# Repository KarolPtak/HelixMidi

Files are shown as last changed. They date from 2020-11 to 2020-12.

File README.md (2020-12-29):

# HelixMidi

## This is a DIY midi footswitch controller for the line6 helix / hx stomp (or actually any midi device).

Short demo: https://youtu.be/-W3b5MKsnIc

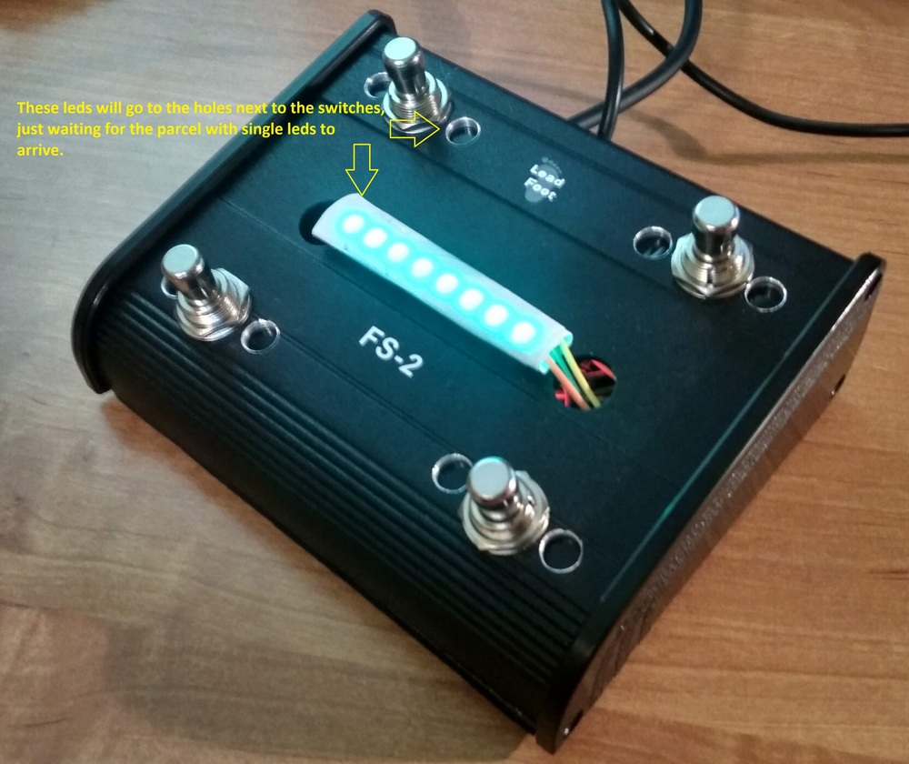
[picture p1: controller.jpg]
Controller


I did it when it's turned out that I neeed more than 3 footswitches ;-) , and the price of stock midi controllers was too high. More likely I'd sell the stomp and buy helix lt instead, if I had to pay for the controller.

It offers 6 different pages (modes), and covers nearly everything that the hx stomp can accept through the midi :)
It is powered directly from USB, works fine with hx stomp, no buzz/hum

- basic - 4 'classic' switches
- basic+ - 3 'classic' switches + tap/tempo
- preset change - Fs4,5 emulation + 1 'classic' + tap/tempo
- snapshot change - 3 snapshot switches + tap/tempo
- looper 1 - record/overdub, play/stop, undo/redo, tap/tempo
- looper 2 - record/overdub, play, stop, undo/redo

- tuner on/off always available when long pressing fs2

## Brief user manual :) :

You can cycle between basic, basic+, preset and snapshot change by long pressing fs1 and fs2 simultaneously.
Clycle between basic, looper 1, looper 2 by long pressing fs3 and fs4 simultaneously.
Each page has it's own color set - I've tried to reflect hx stomp colors as closely as possible :).

Current page is saved in memory, so next time you turn on the controller, it will go back to it.

Footswitch functions in particular page:
- Basic : fs1-4 - 'classic switches' (midi cc codes 100-103)
- Basic+ : fs1-3 - 'classic switches' (midi cc codes 100-102), fs4 - tap/tempo
- Preset change: fs1 - Fs4 emulation, fs2 - 'classic switch' (midi cc code 101), fs3 - Fs5 emulation, fs4 - tap/tempo
- Snapshot change: fs1-3 - snapshot 1-3, fs4 - tap/tempo
- Looper 1 - fs1: play/stop, fs2 - undo/redo, fs3 - record/overdub, fs4 - tap/tempo
- Looper 2 - fs1: stop, fs2 - undo/redo, fs3 - play, fs4 - record/overdub

In the looper modes leds function is a bit different, and it displays if the looper is active, and if record/overdub is in progres.
So eg. after hitting record/overdub (first time) leds indicating looper and record activation will be lit, and then, if You hit the play switch, the record led will be shut. However it's not 100% accurate - (eg. undo/redo hit just after recording is started for the first time seems to turn the looper in the hx stomp off, but it's the best I could do ;-)

Tap tempo blinking - sadly my led blinking implementation did not keep up the same tempo as the stomp. Probably it was implemented too naive way ;), or just a real time clock is needed to do it? hmm...

## Programming

3 external libraries are used for midi, ledstrip and button handling. You can add them via Arduino IDE -> Tools -> Manage Libraries...

Add:
- MIDI Library (by Francois Best, lathoub)
- Freenove WS2812B RGBLED Controller
- ezButton

Sketch uses 8194 bytes (26%) of program storage space. Maximum is 30720 bytes.
Global variables use 740 bytes (36%) of dynamic memory, leaving 1308 bytes for local variables. Maximum is 2048 bytes.

## Elements used

- Arduino nano - https://www.ebay.com/itm/ATmega328P-Micro-Controller-CH340G-Driver-For-Arduino-5V-16MHz-Nano-V3-0-USB/283932008665
- 4 Footswitches - https://www.ebay.com/itm/2Pin-SPST-Momentary-Touch-Push-Button-Stomp-Foot-Pedal-Electric-Guitar-Switch-SC/163157135937
- Ledstrip WS2812B - 8 leds in series, 2 per one switch - like these, just cut it to single leds (they are ready for this): https://www.ebay.com/itm/WS2812B-5V-5050-RGB-LED-Strip-1-5M-30-60-144-150-300-Leds-Individual-Addressable/254700428516
- Case (any, actually) - I used that: https://www.thomann.de/pl/lead_foot_fs2.htm
- Midi cable / socket - I used that: https://www.thomann.de/pl/the_sssnake_sk366-1_blk_midi_kabel.htm and soldered its wires to arduino

Total cost of elements (except the case) was c.a. 23$.

## Wiring
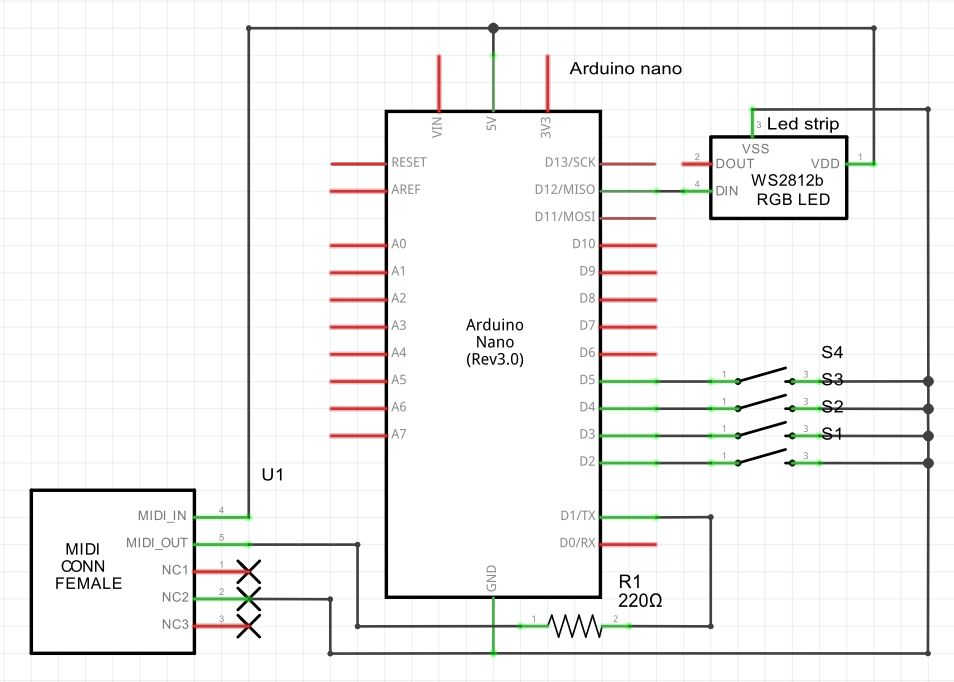
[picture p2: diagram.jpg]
Diagram


In my case (huh, 'case' ;D) the wiring looks like this - pretty simple (only on the photo it looks like hundreds of wires :P ), the arduino is in a heat shrink tubing, and attached to the case with double sided tape

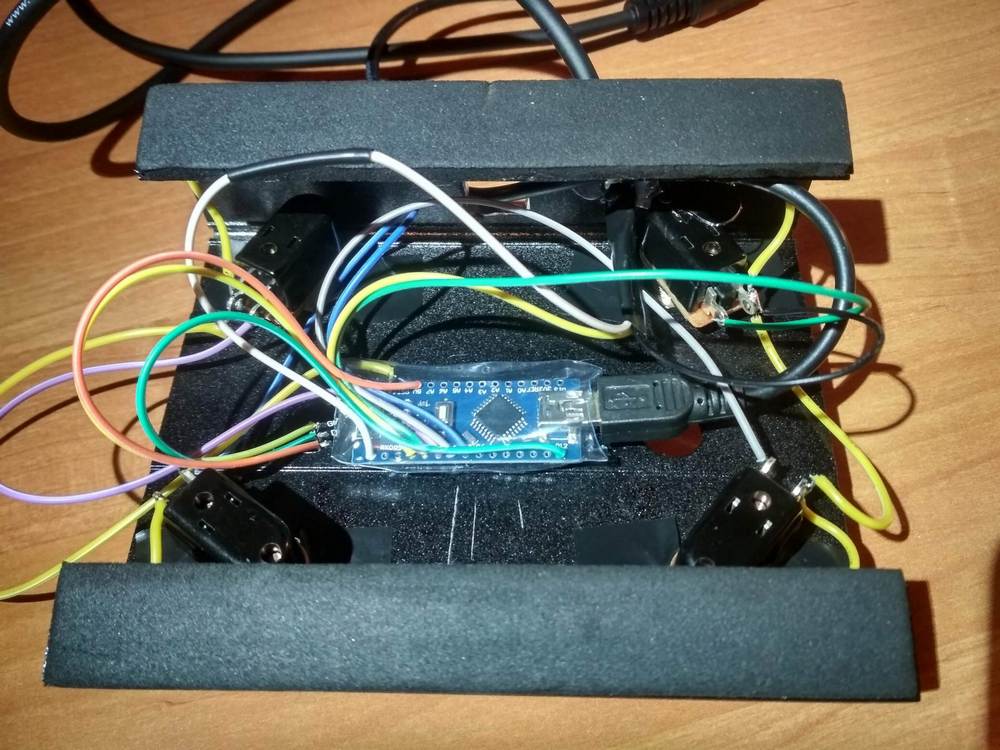
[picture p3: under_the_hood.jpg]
Wiring


## Misc

- If you wonder what is the correct order of pins in the midi socket/plug, this image should solve Your problems (helped me a lot)

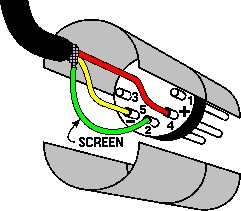
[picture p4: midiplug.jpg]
Midi plug
  
  
  it comes from http://www.philrees.co.uk/midiplug.htm 
  
- It looks like this together with the hx stomp

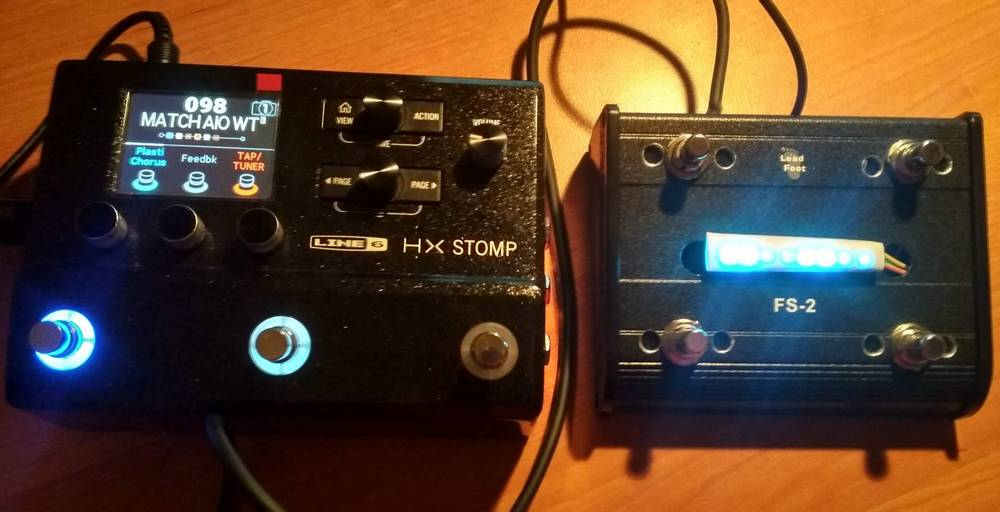
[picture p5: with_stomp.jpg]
Together with hx stomp With hx stomp
  

## TODO

- [ ] Tap/tempo and looper mode
- [ ] Install single leds next to the stomp when they arrive ;) And fill their holes with some transparent, or opaline resin to disperse the led light gently.

## Info from hx stomp instruction

CC message ids restricted by line6 (special purpose):

```
0	n/a Bank MSB (unused, but reserved)
1	0-127 Emulates EXP 1 Pedal
2	0-127 Emulates EXP 2 Pedal
3	0-127 Additional global MIDI commands
32	n/a Bank LSB (unused, but reserved)
49	0-127 Emulates FS1
50	0-127 Emulates FS2
51	0-127 Emulates FS3
52	0-127 Emulates FS4
53	0-127 Emulates FS5
54	0-127 Additional global MIDI commands
55	0-127 Additional global MIDI commands
56	0-127 Additional global MIDI commands
57	0-127 Additional global MIDI commands
58	0-127 Additional global MIDI commands
59	0-127 Additional global MIDI commands
60	0-63: Overdub;64-127: Record 1 Switch Looper Record/Overdub
61	0-63: Stop;64-127: Play 1 Switch Looper Play/Stop
62	64-127 1 Switch Looper Play Once
63	64-127 1 Switch Looper Undo/Redo
64	64-127 Tap Tempo
65	0-63: Forward; 64-127: Reverse 1 Switch Looper Forward/Reverse
66	0-63: Full; 64-127: Half 1 Switch Looper Full/Half Speed
67	0-127 Additional global MIDI commands
68	0-127 Tuner screen on/off
69	0-2, 8 and 9 Snapshot select (0=Snapshot 1, 1=Snapshot 2, 2=Snapshot 3, 8=Next snapshot, 9=Previous snapshot)
70	0-63: Bypass; 64-127: On All Bypass
71	0-5 Footswitch Mode (0=Stomp, 1=Scroll, 2=Preset, 3=Snapshot, 4=Next footswitch mode, 5=Previous footswitch mode)
72	0-127 Additional global MIDI commands
73	0-127 Additional global MIDI commands
74	0-127 Additional global MIDI commands
75	0-127 Additional global MIDI commands
76	0-127 Additional global MIDI commands
128	 0-63: Jealous;  64-127: Codependent HX Stomp sends late-night texts to all of your exsignificant others, professing your undying love to them and their cats
```

Values for block bypass
```
Incoming CC values 0-63 turn the block off; values 64-127 turn the block on. Note
that some MIDI CCs are reserved for global functions and cannot be selected 
```

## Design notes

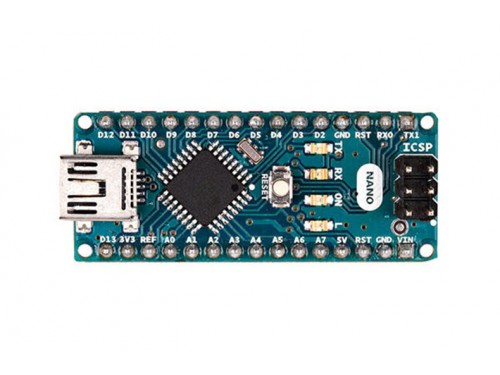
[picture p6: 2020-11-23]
arduino_nano.jpg

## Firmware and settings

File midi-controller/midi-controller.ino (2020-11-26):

#include <ezButton.h>
#include <PololuLedStrip.h>
#include <MIDI.h>
#include "BasePage.h"
#include "globals.h"
#include "PagePersister.h"


//BUTTONS
ezButton button1(2);  // create ezButton object that attach to pin;
ezButton button2(3);  
ezButton button3(4);  
ezButton button4(5);  

unsigned long button1Time = 0;
unsigned long button2Time = 0;
unsigned long button3Time = 0;
unsigned long button4Time = 0;

//MIDI
MIDI_CREATE_DEFAULT_INSTANCE();

//OTHER
unsigned long time = 0;


//PAGES
BasicPage _basicPage;
BasicPlusTapTempoPage _basicPlusTapTempoPage;
PatchChangePage _patchChangePage;
SnapshotChangePage _snapshotChangePage;
LooperPage _looperPage;
Looper2Page _looper2Page;

BasePage *_page;

PagePersister pagePersister;

void setup() {
  pinMode(LED_PIN, OUTPUT);   // set arduino pin to output mode

  button1.setDebounceTime(debounceTime);
  button2.setDebounceTime(debounceTime); 
  button3.setDebounceTime(debounceTime); 
  button4.setDebounceTime(debounceTime); 
  
  MIDI.begin(midiChannel);
  pagePersister.init();
  _page = getPage(pagePersister.get());

  _page->setup();
}

void loop() {
  button1.loop(); // MUST call the loop() function first
  button2.loop(); 
  button3.loop(); 
  button4.loop(); 
  _page->loop();


  if(button1.isPressed())
    button1Time = millis();
  if(button2.isPressed())
    button2Time = millis();
  if(button3.isPressed())
    button3Time = millis();
  if(button4.isPressed())
    button4Time = millis();

  if(button1.isReleased())
    button1Time = 0;
  if(button2.isReleased())
    button2Time = 0;
  if(button3.isReleased())
    button3Time = 0;
  if(button4.isReleased())
    button4Time = 0;


  if(button1Time && button2Time) {
    time = millis();
    boolean exited = false;
    while(millis() - time < twoButtonTimeout && !exited) //we can stop waiting sooner if buttons are released
      exited = button1.getStateRaw() == HIGH || button2.getStateRaw() == HIGH;

    if(!exited) { //if before twoButtonTimeout any of buttons is depressed, do not trigger two button action
      //these 2 buttons switch enter to basicPlusTapTempoPage and patchChangePage pages
      switch(_page->id()){
        case BASICPLUSTAPTEMPOPAGE:
          _page = &_patchChangePage;
          break;
        case PATCHCHANGEPAGE:
          _page = &_snapshotChangePage;
          break;
        case SNAPSHOTCHANGEPAGE:
          _page = &_basicPage;
          break;
        default:
          _page = &_basicPlusTapTempoPage; //if current page is basic or not from this subset, then go to first page from this subset
          break;
      }

      pagePersister.update(_page->id());
      _page->setup();
    }

    clearTimes(); //we 'consumed' current buttons hits
  }

  if(button3Time && button4Time) {
    time = millis();
    boolean exited = false; //will such a local variable cause memory allocation and memory leak in over a time? I'm asking, 'cause I'm a C# programmer on daily basis ;).
    while(millis() - time < twoButtonTimeout && !exited) //we can stop waiting faster if buttons are released
      exited = button3.getStateRaw() == HIGH || button4.getStateRaw() == HIGH;

    if(!exited) { //if before twoButtonTimeout any of buttons is depressed, do not trigger two button action
      switch (_page->id()) {
        case LOOPERPAGE:
          _page = &_looper2Page;
          break;
        case LOOPER2PAGE:
          _page = &_basicPage;
          break;
        default:
          _page = &_looperPage;
          break;
      }

      pagePersister.update(_page->id());
      _page->setup();
    }

    clearTimes();    
  }  

  if(millis() - button1Time > singleButtonTimeout && button1Time && !button2Time && !button3Time && !button4Time) { // if only first button is pressed, and is pressed for at least singleButtonTimeout miliseconds
    _page->button1Action();
    clearTimes();
  }

  if(millis() - button2Time > singleButtonTimeout && !button1Time && button2Time && !button3Time && !button4Time) {
    time = millis();
    boolean exited = false; //will such a local variable cause memory allocation and memory leak in over a time? I'm asking, 'cause I'm a C# programmer on daily basis ;).
    while(millis() - time < twoButtonTimeout && !exited)
      exited = button2.getStateRaw() == HIGH;    

    _page->button2Action(!exited);
    clearTimes();
  }
  
  if(millis() - button3Time > singleButtonTimeout && !button1Time && !button2Time && button3Time && !button4Time) {
    _page->button3Action();
    clearTimes();
  }

  if(millis() - button4Time > singleButtonTimeout && !button1Time && !button2Time && !button3Time && button4Time) {
    _page->button4Action();
    clearTimes();
  }      
}

void clearTimes() {
  button1Time = 0;
  button2Time = 0;
  button3Time = 0;
  button4Time = 0;
}

BasePage* getPage(int pageId) {
  switch (pageId) {
  case BASICPAGE:
    return &_basicPage;
  case BASICPLUSTAPTEMPOPAGE:
    return &_basicPlusTapTempoPage;
  case PATCHCHANGEPAGE:
    return &_patchChangePage;
  case SNAPSHOTCHANGEPAGE:
    return &_snapshotChangePage;
  case LOOPERPAGE:
    return &_looperPage;
  case LOOPER2PAGE:
    return &_looper2Page;
  default:
    return &_basicPage;
  }
}

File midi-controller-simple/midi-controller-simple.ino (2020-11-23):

#include <ezButton.h>
#include <PololuLedStrip.h>
#include <MIDI.h>


//BUTTONS
ezButton button1(2);  // create ezButton object that attach to pin;
ezButton button2(3);  // create ezButton object that attach to pin;
ezButton button3(4);  // create ezButton object that attach to pin;
ezButton button4(5);  // create ezButton object that attach to pin;

int button1State = LOW;   // the current state of stomp button
int button2State = LOW;   // the current state of stomp button
int button3State = LOW;   // the current state of stomp button
int button4State = LOW;   // the current state of stomp button


//MIDI
MIDI_CREATE_DEFAULT_INSTANCE();
const int midiChannel = 1;
const int midiCc1 = 100;
const int midiCc2 = 101;
const int midiCc3 = 102;
const int midiCc4 = 103;

const int midiLowValue = 0;
const int midiHighValue = 127;


//LEDSTRIP
#define LED_COUNT 8 

PololuLedStrip<12> ledStrip; // Create an ledStrip object and specify the pin it will use.
rgb_color colors[LED_COUNT]; //buffer for holding the colors (3 bytes per color).
const int ledHue = 130;
const int ledSat = 255;
const int ledDim = 10;
const int ledBright = 110;


//OTHER
const int LED_PIN    = 13; // the number of the LED pin




void setup() {
  pinMode(LED_PIN, OUTPUT);   // set arduino pin to output mode

  button1.setDebounceTime(50); // set debounce time to 50 milliseconds
  button2.setDebounceTime(50); // set debounce time to 50 milliseconds
  button3.setDebounceTime(50); // set debounce time to 50 milliseconds
  button4.setDebounceTime(50); // set debounce time to 50 milliseconds
  
  MIDI.begin(midiChannel);
  UpdateLedStrip();
}

void loop() 
{
  button1.loop(); // MUST call the loop() function first
  button2.loop(); // MUST call the loop() function first
  button3.loop(); // MUST call the loop() function first
  button4.loop(); // MUST call the loop() function first

  if(button1.isPressed()) 
  {
    button1State = !button1State; // toggle button's state
    digitalWrite(LED_PIN, button1State); //that's only for debugging
    MIDI.sendControlChange(midiCc1, button1State == LOW ? midiLowValue : midiHighValue, midiChannel);
    UpdateLedStrip();
  }

  if(button2.isPressed()) 
  {
    button2State = !button2State; // toggle button's state
    MIDI.sendControlChange(midiCc2, button2State == LOW ? midiLowValue : midiHighValue, midiChannel);
    UpdateLedStrip();
  }
  
  if(button3.isPressed()) 
  {
    button3State = !button3State; // toggle button's state
    MIDI.sendControlChange(midiCc3, button3State == LOW ? midiLowValue : midiHighValue, midiChannel);
    UpdateLedStrip();
  }

  if(button4.isPressed()) 
  {
    button4State = !button4State; // toggle button's state
    MIDI.sendControlChange(midiCc4, button4State == LOW ? midiLowValue : midiHighValue, midiChannel);
    UpdateLedStrip();
  }      
}




void UpdateLedStrip()
{
    //led strip is temporaliry mounted upside down, so leds go in order from right to left, so need to reverse here too
    colors[0] = hsvToRgb(ledHue, ledSat, button4State == LOW ? ledDim : ledBright);
    colors[1] = hsvToRgb(ledHue, ledSat, button4State == LOW ? ledDim : ledBright);
    colors[2] = hsvToRgb(ledHue, ledSat, button3State == LOW ? ledDim : ledBright);
    colors[3] = hsvToRgb(ledHue, ledSat, button3State == LOW ? ledDim : ledBright);
    colors[4] = hsvToRgb(ledHue, ledSat, button2State == LOW ? ledDim : ledBright);
    colors[5] = hsvToRgb(ledHue, ledSat, button2State == LOW ? ledDim : ledBright);
    colors[6] = hsvToRgb(ledHue, ledSat, button1State == LOW ? ledDim : ledBright);
    colors[7] = hsvToRgb(ledHue, ledSat, button1State == LOW ? ledDim : ledBright);

    ledStrip.write(colors, LED_COUNT);  
}

// Converts a color from HSV to RGB.
// h is hue, as a number between 0 and 360.
// s is the saturation, as a number between 0 and 255.
// v is the value, as a number between 0 and 255.
rgb_color hsvToRgb(uint16_t h, uint8_t s, uint8_t v)
{
    uint8_t f = (h % 60) * 255 / 60;
    uint8_t p = (255 - s) * (uint16_t)v / 255;
    uint8_t q = (255 - f * (uint16_t)s / 255) * (uint16_t)v / 255;
    uint8_t t = (255 - (255 - f) * (uint16_t)s / 255) * (uint16_t)v / 255;
    uint8_t r = 0, g = 0, b = 0;
    switch((h / 60) % 6){
        case 0: r = v; g = t; b = p; break;
        case 1: r = q; g = v; b = p; break;
        case 2: r = p; g = v; b = t; break;
        case 3: r = p; g = q; b = v; break;
        case 4: r = t; g = p; b = v; break;
        case 5: r = v; g = p; b = q; break;
    }
    return rgb_color(r, g, b);
}

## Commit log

2020-11-23 make the arduino ide happy and move files to folder that matches the .ino file name
2020-11-23 add images
    [diagram.fzz]
2020-11-26 add page change - detect two buttons pressed simultaneously
2020-11-26 extract button action handling to page specific classes
2020-11-26 make the button state and leds control a private page thing
2020-11-26 add tap/tempo led blinking
2020-11-26 add second looper page with all 4 buttons dedicated to looper control
2020-11-26 add led color to indicate tuner option
2020-11-26 change leds order after fixing ledstrip orientation
